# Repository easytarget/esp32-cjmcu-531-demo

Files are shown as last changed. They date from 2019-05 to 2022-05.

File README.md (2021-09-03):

 `y'know Travis is beginning to tick me off`

# CJMCU-531 and ESP32 Demo using a VL53L1X library and Ajax to display on a self-hosted site.
## A crude, slow(ish), low fidelity Lidar system
 
Designed (initially) for the commonly available VL53L1X (4 meter) IR Time Of Flight sensor from ST Microelectronics:
https://www.st.com/en/imaging-and-photonics-solutions/vl53l1x.html

Using this in can be as easy as connecting to the `VL53L1X-demo` wifi network (no password needed), and then browsing to `192.168.4.1` for the UI. Other WiFi settings can be used of course, see comments.

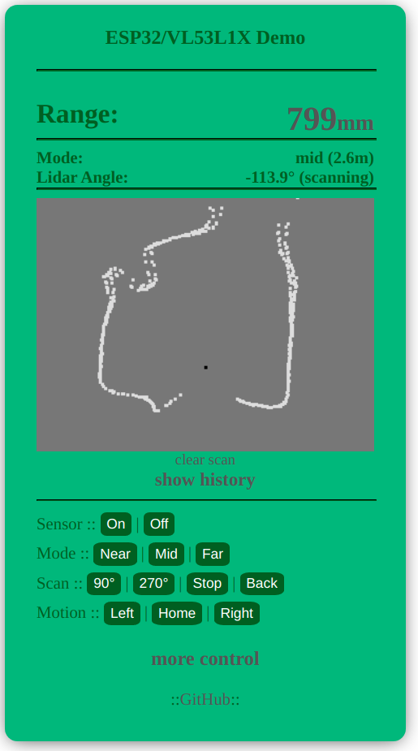
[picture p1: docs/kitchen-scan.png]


The goal of this project is to prove the suitability of this sensor for a small-scale LIDAR scanner to be used in domestic automation; robot vaccum cleaners, security robots, monitoring systems and, in my case, a K9 'companion' robot I am working on as a long-term plan.

The VL53L1X is just one of a range of similar Time-Of-Flight sensors from ST Micro. This sketch should be easily adaptable for them all, and other manufacturers have their own sensors which may also be suitable.

I have been pleasently surprised that the results are better than I expected; the scan above is of my Kitchen; here is what it looks like in reality, the sensor is the little black dot in the scan, and the little red light in the photo.

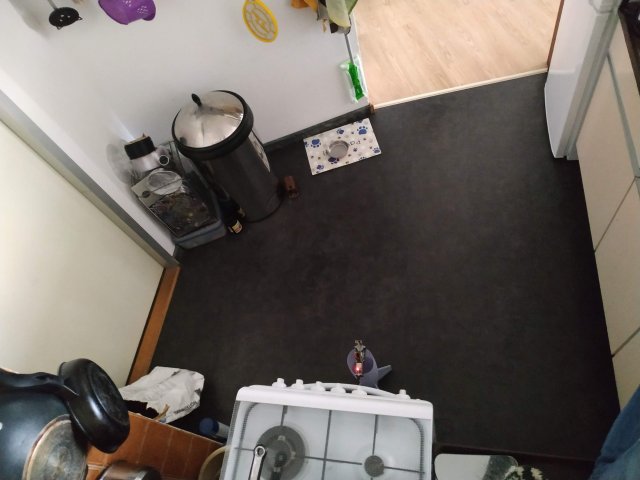
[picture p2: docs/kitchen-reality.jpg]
The Source


### Requirements:
#### Hardware:`
* ESP32 DEV module connected to a suitable sensor module; any ESP 32 module should be suitable, but you may need to adapt pinouts.
* I use a CJMCU-531 sensor carrier module, these are freely available online from AliExpress and the like. There are other VL53L1 carrier modules and boards available, all should work with this.
* For the LIDAR scan mechanism I have a 5V stepper motor with gearbox, plus the H-Bridge control board supplied with it. These are very common and can be found on AliExpress, Ebay, hobby electronics stores etc. for a couple of Euros.

#### Software:
I use the standard Arduino IDE to develop and program the unit. You need to install the ESP development board definitions and libraries using the instructions at https://docs.espressif.com/projects/arduino-esp32/en/latest/installing.html

The following 3rd party libraries are needed. They are not installed as standard in the Arduino IDE but are searchable and installable from within the library manager.
* Sparkfun VL53L1X library: https://github.com/sparkfun/SparkFun_VL53L1X_Arduino_Library/
* ArduinoJson library (v1.6+): https://arduinojson.org/

Select the dev board you are using from the boards manager list (normally the default generic ESP32 dev board entry) and select 'Minimal SPIFFS (1.9MB app with OTA..)' as your partition table type unless you have disabled Over The Air updates. See [this](/docs/programming.png).

By default the unit will create a passwordless AccessPoint named `VL53L1X-demo`, you can connect to that and browse to `http://192,168,4,1/` to see the demo. Alternatively rename the file `mywifi.sample.h` to `mywifi.h` and fill in your own details to connect to existing networks or make a more secure AP.

### A note on Sensor Libraries
Currently I use the Sparkfun library; but there is also one from Pololu: https://github.com/pololu/vl53l1x-arduino & https://www.pololu.com/product/3415/resources

Both of these are 'light' libs designed for ATMega arduinos (eg limited RAM, etc). The Official ST lib is larger, but more complete and (arguably) better supported. It is also somewhat crankily documented, and requires a sign-up at stmicro .com to access.

The ST lib itself is redistributable, although the detailed documentation is not.. I still plan to move to this; and will provide it with the codebase here.
See: https://www.st.com/en/ecosystems/x-cube-53l1a1.html#overview

### Construction

A rather minimalist guide here, I'm afraid. I have a more descriptive set of instructions, phopos and a parts list on the Hackaday page for this project:
https://hackaday.io/project/168327-cheap-and-cheerful-lidar-demo-and-dev-system

You need to follow the pinout guide here to connect the sensor and your development board together. Similarlarly for the stepper and it's H-Board driver card. And you need to maount the boards and sensor somehow. A simple design for 3d-printing with a 51x28mm 15 pin/side devboard is in the repo, as is a scadfile that can be adapted for other sizes of board(s), see line (#32)[https://github.com/easytarget/esp32-cjmcu-531-demo/blob/master/3dPrints/lidar-stand.scad#L32] for dimensioning.

#### Pins:
1. **3v3** on ESP32 goes to **VCC** on CJMCU-531
1. **GND** on ESP32 goes to **GND** on CJMCU-531
1. **D21** (GPIO21, I2C SDA) on ESP32 goes to **SDA** on CJMCU-531
1. **D22** (GPIO22, I2C SCL) on ESP32 goes to **SCL** on CJMCU-531

Not currently used, but would be required for multi-sensor or low power sentinel use.

5. _**D5** (GPIO5) on ESP32 goes to **XSHUT** on CJMCU-531 (shutdown control)_
5. _**D18** (GPIO18) on ESP32 goes to **GPIO1** on CJMCU-531 (interrupt line)_

If you are using a H-bridge driven Servo the default pins (easily changable in code) are:

7. _**D27**_ (GPIO27), _**D25**_ (GPIO25), _**D26**_ (GPIO26), _**D33**_ (GPIO23) on ESP32 should go to the respective 1,2,3,4, inputs on the H-Bridge driver.
7. **5v** and **GND** on the ESP32 are used for the stepper power supply; this places a reasonable demand on the USB power supply. Lockups and disconnects associated with motor movement are undoubtedly caused by the USB supply dipping and causing brownouts, use a decent PSU and cable.

### Demo setup
The WebUI for the demo is optimised for mobile phone displays, I run the unit in AP mode and connect from my Mobile. This allows me to demo to others easily too. 
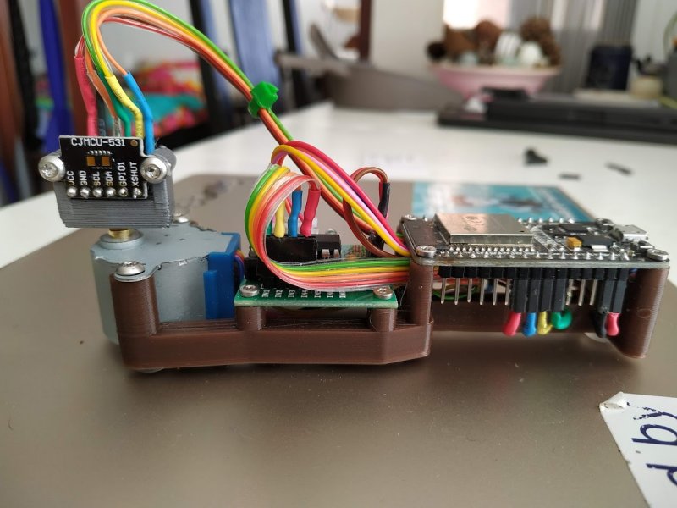
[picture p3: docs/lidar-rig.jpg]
The Prototype


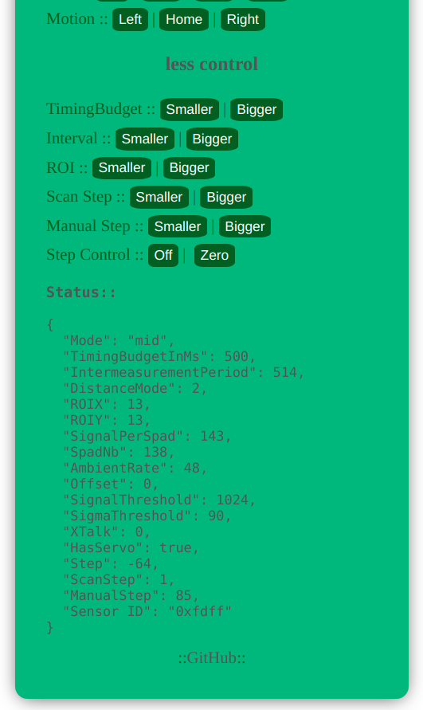
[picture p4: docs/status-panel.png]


### Future Plans
https://github.com/easytarget/esp32-cjmcu-531-demo/issues
* Move to the Official ST micro libs
* SMP: handle sensor+servo on different core than the web server.
* stop using GET requests and move to a streaming protocol.

#### Contributing
* Fork the repo
* Make a branch with a sensible nraeme in your forked repo and commit changes to that
* Make a PR in this repo against your remote fork and branch
* Explain what you are doing and don't be slapdash.. I hate random.

### Issues
The scanning action is driven by successful sending of the data to the web client. It is affected by network timeouts, packet drops and delays, these will make the scan action intermittent and somewhat laggy.. This would be resolved by implementing the data stream/smp plans above.

I have noticed the CJMCU-531 I2C comms seem to lock up infrequently, and needed a full power cycle to resume. This has only happened when I'm reflashing, rebooting and developing heavily; it seems stable when left in operation and not being 'messed' with. 

### Base/Stand/Bracket
I have included model files I used for my development board (JoyIT NodeMCU) and a paramatised SCAD file that can accomodate other MCU and Stepper driver board sizes by adjusting the relevant settings.

Two different sensor mounts are provided; the v2(taller) one also mounts the sensor at a slight angle to avoid rangefinding the edge of the table, I have found that for best results I need to stand the unit on a box or vase.
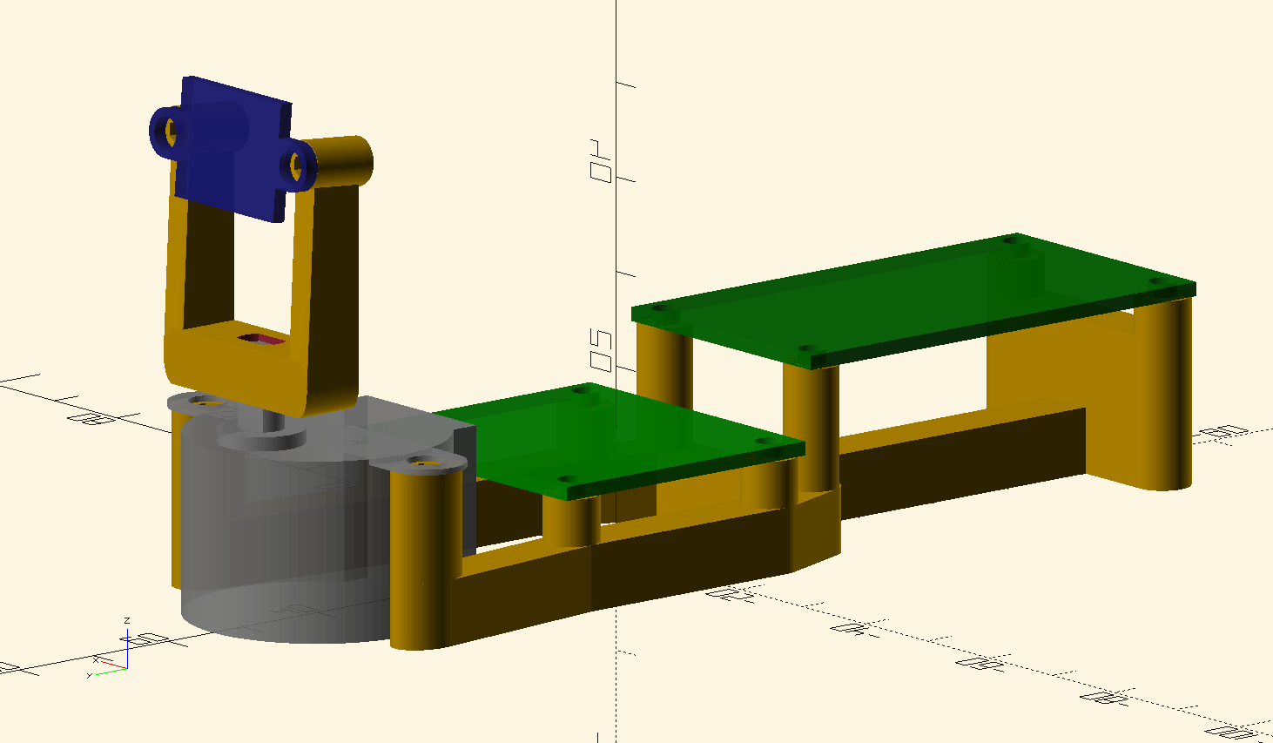
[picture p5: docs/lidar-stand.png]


### EndGoal:
Use a ESP32-CAM instead of the dev board, stream video, take pictures, record ranges all in one.

Then link that via Serial and level converters to a ATMega328 based robot chassis I already have; and go for a WiFi drive.
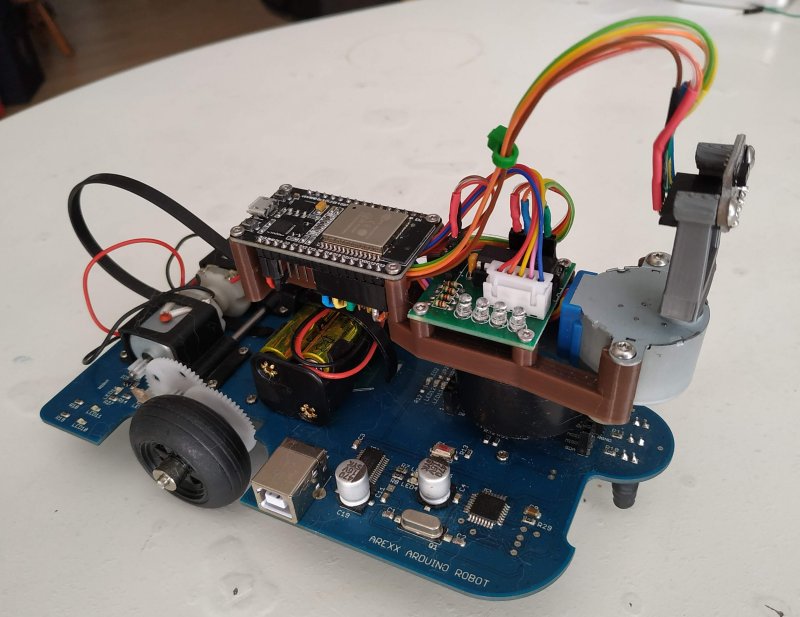
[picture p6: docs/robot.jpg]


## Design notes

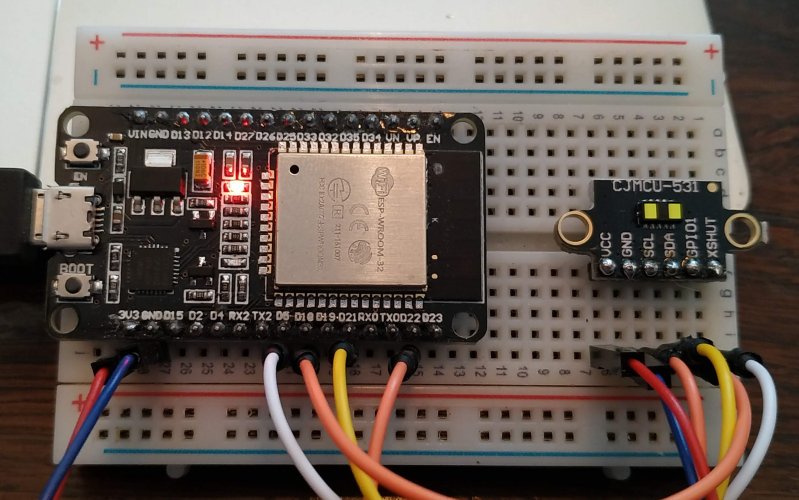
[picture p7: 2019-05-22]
docs/rangefinder-proto1.jpg

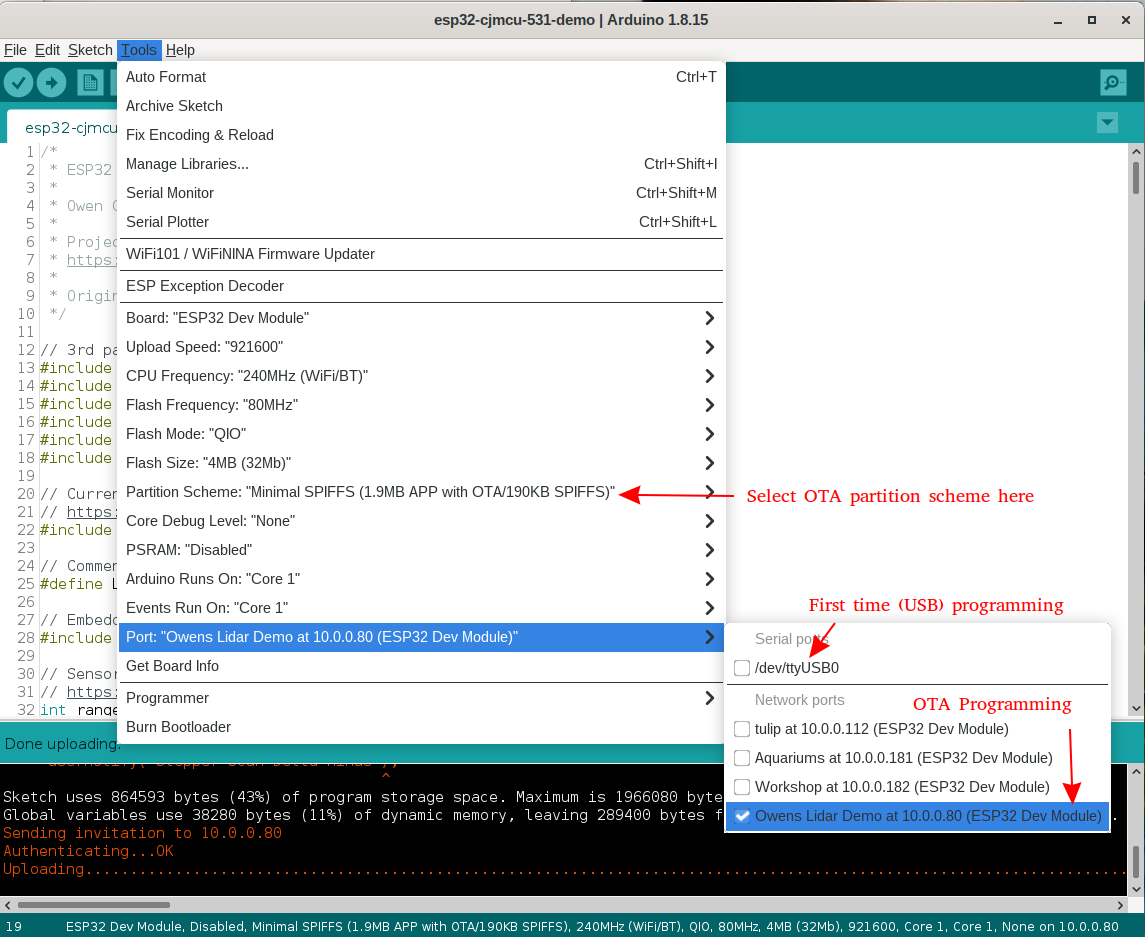
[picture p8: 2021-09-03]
docs/programming.png

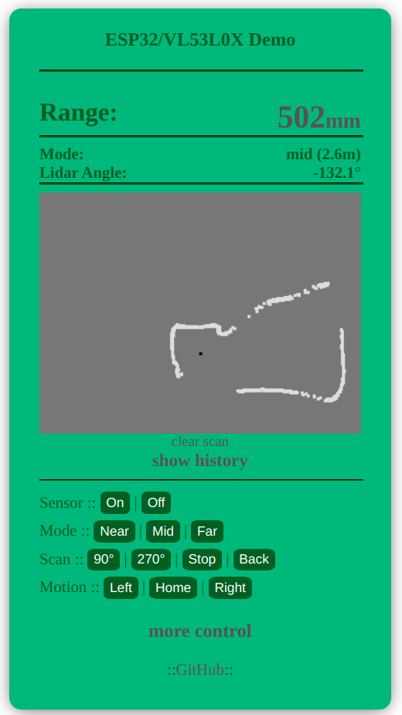
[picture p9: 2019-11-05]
docs/graph-panel.png

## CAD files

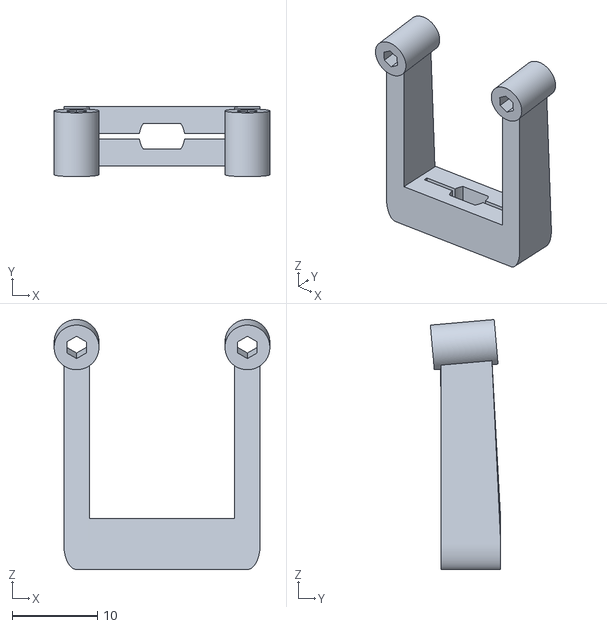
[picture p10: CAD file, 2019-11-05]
3dPrints/lidar-stand-mount-v2.stl
25.2 x 8.23 x 29.3

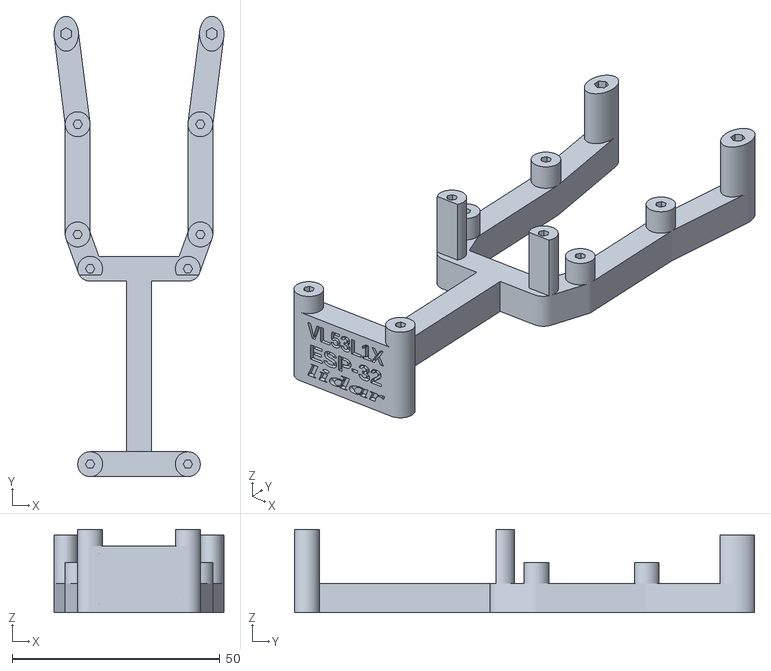
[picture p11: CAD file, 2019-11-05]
3dPrints/lidar-stand-base.stl
40.9 x 110.7 x 20.0

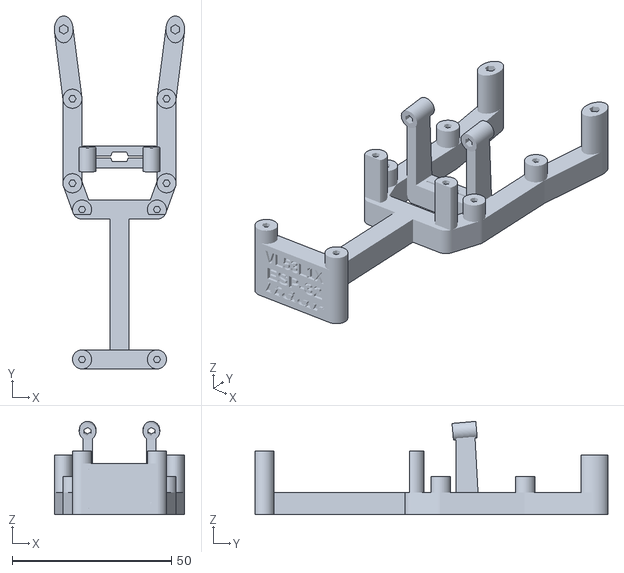
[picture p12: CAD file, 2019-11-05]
3dPrints/lidar-stand-set.stl
40.9 x 110.7 x 29.3

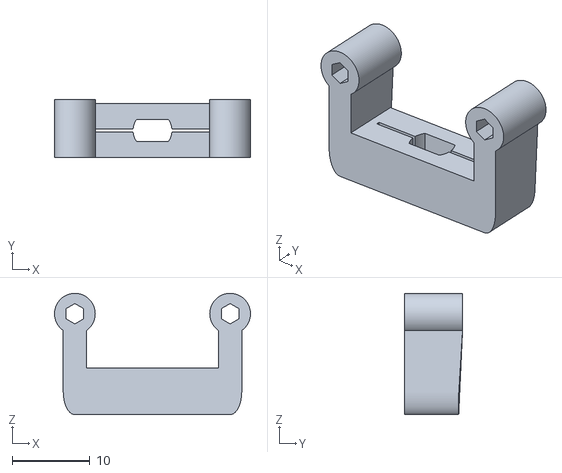
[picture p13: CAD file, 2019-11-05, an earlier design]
3dPrints/lidar-stand-mount-v1.stl
25.2 x 7.50 x 15.6

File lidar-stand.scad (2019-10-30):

// Lidar Base
// A bit overdone, but works OK. 
// Wayyy too many parameters, but Boards are resizable
//  and can be moved relative to each other.

$fn=90;

fitting=!true;

stand();

mcuY = -40;
drvY = 5;
motY = 40;
// tofs prefix used for flight sensor


if (fitting) 
    mount(pos=[0,motY+motsoffset-3.5,40],rot=-90);
else
    mount([0,-3.5,16],-90); 
    
if (fitting) {
    color("darkgreen",0.8) mcu(pos=[0,mcuY,20]);
    color("green",0.8) drv(pos=[0,drvY,12]);
    color("grey",0.8) mot(pos=[0,motY,0]);
    color("midnightblue",0.8) tof(pos=[0,motY+motsoffset+5.5,37]);
}

// Parts & Dimensions

mcuholeX=23.5;
mcuholeY=47;
mcuholeD=3;
mcuboardX=28.7;
mcuboardY=51.7;

drvholeX=29.5;
drvholeY=26.5;
drvholeD=3;
drvboardX=34.5;
drvboardY=32;

motdia=28;
mothigh=19.25;
motwireout=17.5;
motholeW=35;
motholeD=4.2;
motshaft=5;
motsflat=3;
motsoffset=7.5;
motsbossD=9.3;
motsl=8.5; 

tofsholeW=20;
tofsholeD=3.5;
tofsboardH=12.5;
tofsboardW=15.8;



module mount(pos=[0,0,0],rot=0) 
    translate(pos) rotate([rot,0,0]) {
    linear_extrude(height=7.5) {
        translate([-tofsholeW/2,3])
        difference() {
            circle(d=tofsholeD*1.5);
            rotate(30) circle(d=tofsholeD*0.75,$fn=6);
        }
        translate([tofsholeW/2,3])
        difference() {
            circle(d=tofsholeD*1.5);
            rotate(30) circle(d=tofsholeD*0.75,$fn=6);
        }
    }
    difference() {
        hull () {
            translate([10,13,0]) scale([0.5,1,1])
            cylinder(d=6,h=7);
            translate([-10,13,0]) scale([0.5,1,1])
            cylinder(d=6,h=7);
        }
        translate([0,13,3.5])
        rotate([90,0,0])
        intersection() {
            cylinder(d=motshaft,h=7,center=true);
            cube([motshaft,motsflat-0.2,7],center=true);
        }
        translate([0,13,3.5])
        cube([15,7,0.4],center=true);
    }
    hull () {
        translate([10,13,0]) scale([0.5,1,1])
        cylinder(d=6,h=7);
        translate([10,5,0]) scale([1,0.1,1])
        cylinder(d=3,h=7.5);
    }
    hull () {
        translate([-10,13,0]) scale([0.5,1,1])
        cylinder(d=6,h=7);
        translate([-10,5,0]) scale([1,0.1,1])
        cylinder(d=3,h=7.5);
    }
}
    

module stand() {
    // motor pins
    translate([0,motY,0])
    linear_extrude(height=mothigh-0.6) {
        for(x=[-0.5,0.5]) {
            translate([motholeW*x,0])
            difference() {
                scale([0.7,1]) circle(r=motholeD);
                rotate(30) circle(d=motholeD*0.7,$fn=6);
            }
        }
    }

    // driver pins
    translate([0,drvY,0])
    linear_extrude(height=12) {
        for(x=[-0.5,0.5],y=[-0.5,0.5]) {
            translate([drvholeX*x,drvholeY*y])
            difference() {
                circle(r=drvholeD);
                circle(d=drvholeD*0.75,$fn=6);
            }
        }
    }
        
    // mcu pins
    translate([0,mcuY,0]) 
    linear_extrude(height=20) difference() {
            for(x=[-0.5,0.5],y=[-0.5,0.5]) {
                translate([mcuholeX*x,mcuholeY*y])
                difference() {
                    circle(r=mcuholeD);
                    circle(d=mcuholeD*0.75,$fn=6);
                }
            }
            translate([-mcuboardX,mcuholeY/2-7])
            square([mcuboardX*2,5.5]);
    }

    // chassis, hull city
    linear_extrude(height=7) {
        hull() {
            translate([mcuholeX/2,mcuholeY/2+mcuY])
            circle(r=mcuholeD);
            translate([-mcuholeX/2,mcuholeY/2+mcuY])
            circle(r=mcuholeD);
        }
        hull() {
            translate([mcuholeX/2,mcuholeY/2+mcuY])
            circle(r=mcuholeD);
            translate([drvholeX/2,-drvholeY/2+drvY])
            circle(r=drvholeD);
        }
        hull() {
            translate([-mcuholeX/2,mcuholeY/2+mcuY])
            circle(r=mcuholeD);
            translate([-drvholeX/2,-drvholeY/2+drvY])
            circle(r=drvholeD);
        }
        hull() {
            translate([drvholeX/2,drvholeY/2+drvY])
            circle(r=drvholeD);
            translate([drvholeX/2,-drvholeY/2+drvY])
            circle(r=drvholeD);
        }
        hull() {
            translate([-drvholeX/2,drvholeY/2+drvY])
            circle(r=drvholeD);
            translate([-drvholeX/2,-drvholeY/2+drvY])
            circle(r=drvholeD);
        }
        hull() {
            translate([-drvholeX/2,drvholeY/2+drvY])
            circle(r=drvholeD);
            translate([-motholeW/2,motY])
            scale([0.7,1]) circle(r=motholeD);
        }
        hull() {
            translate([drvholeX/2,drvholeY/2+drvY])
            circle(r=drvholeD);
            translate([motholeW/2,motY])
            scale([0.7,1]) circle(r=motholeD);
        }
    }
    difference() {
        union() {
            linear_extrude(height=16,convexity=10)
            hull() {
                translate([mcuholeX/2,mcuY-mcuholeY/2])
                circle(r=mcuholeD);
                translate([-mcuholeX/2,mcuY-mcuholeY/2])
                circle(r=mcuholeD);
            }
            linear_extrude(height=7,convexity=10)
            hull() {
                translate([0,mcuholeY/2+mcuY])
                circle(r=mcuholeD);
                translate([0,-mcuholeY/2+mcuY])
                circle(r=mcuholeD);
            }
        }
        translate([0,mcuY-mcuholeY/2-2,11])
        rotate([90,0,0])
        linear_extrude(height=4,convexity=10)
        scale([0.34,0.35,1])
        text("VL53L1X",halign="center",font="Liberation Sans:style=Bold");
        translate([0,mcuY-mcuholeY/2-2,6])
        rotate([90,0,0])
        linear_extrude(height=4,convexity=10)
        scale([0.4,0.35,1])
        text("ESP-32",halign="center",font="Liberation Sans:style=Bold");
        translate([0,mcuY-mcuholeY/2-2,2])
        rotate([90,0,0])
        linear_extrude(height=4,convexity=10)
        scale([0.75,0.3,1])
        text("lidar",halign="center",font="Liberation Serif:style=Bold Italic");
   }
}


module mcu(pos=[0,0,0]) translate(pos) {
    linear_extrude(height=1.5) {
        difference() {
            square([mcuboardX,mcuboardY],center=true);
            for (x=[-0.5,0.5],y=[-0.5,0.5]) {
                translate([mcuholeX*x,mcuholeY*y])
                circle(d=mcuholeD);
            }
        }
    }
}

module drv(pos=[0,0,0]) translate(pos) {
    linear_extrude(height=1.5) {
        difference() {
            square([drvboardX,drvboardY],center=true);
            for (x=[-0.5,0.5],y=[-0.5,0.5]) {
                translate([drvholeX*x,drvholeY*y])
                circle(d=drvholeD);
            }
        }
    }
}

module mot(pos=[0,0,0]) translate(pos) {
    linear_extrude(height=mothigh) {
        circle(d=motdia);
        translate([0,-motdia/2+2])
        square([motwireout,4],center=true);
    }
    translate([0,0,mothigh-0.6])
    linear_extrude(height=0.6) {
        difference() {
            hull() {
                translate([-motholeW/2,0])
                circle(r=motholeD);
                translate([motholeW/2,0])
                circle(r=motholeD);
            }
            translate([-motholeW/2,0])
            circle(d=motholeD);
            translate([motholeW/2,0])
            circle(d=motholeD);
        }
    }
    translate([0,motsoffset,mothigh])
    cylinder(d=motsbossD,h=1.5);
    translate([0,motsoffset,mothigh+1.5])
    intersection() {
        cylinder(d=motshaft,h=motsl);
        translate([-motshaft/2,-motsflat/2,0])
        cube([motshaft,motsflat,motsl]);
    }
    
}

module tof(pos=[0,0,0],rot=90) 
    translate(pos) rotate([rot,0,0]) {
    linear_extrude(height=1.5) {
        square([tofsboardW,tofsboardH],center=true);
        difference() {
            hull() {
                translate([-tofsholeW/2,0])
                circle(d=tofsholeD*1.5);
                translate([tofsholeW/2,0])
                circle(d=tofsholeD*1.5);
            }
            translate([-tofsholeW/2,0])
            circle(d=tofsholeD);
            translate([tofsholeW/2,0])
            circle(d=tofsholeD);
        }
    }
}

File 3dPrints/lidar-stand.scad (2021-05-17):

// Lidar Base
// A bit overdone, but works OK. 
// All the dimensions of the Boards are resizable
//  and boards can be moved relative to each other 
//  for clearance.

$fn=90;

// Fitting mode is good for getting the design right
fitting=!false;

// Parts & Dimensions

// ESP32 Dev Board 
// (this can vary, there are many 'standard' dev board layouts for the ESP32)
esp32BoardX=28.7;  // overall board dimensions
esp32BoardY=51.7;
esp32Holex=23.5;   // holes (assume common centre to board)
esp32HoleY=47;
esp32HoleD=3;      // hole diameter

// Stepper Motor H-Bridge driver board
hBridgeBoardX=34.5;
hBridgeBoardY=32;
hBridgeHoleX=29.5;
hBridgeHoleY=26.5;
hBridgeHoleD=3;

// Stepper Motor
stepperMotorDiameter=28;
stepperMotorHeight=19.25;
stepperMotorWireout=17.5;
stepperMotorHoleW=35;
stepperMotorHoleD=4.2;
stepperMotorShaft=5;
stepperMotorShaftFlat=3;
stepperMotorShaftOffset=7.5;
stepperMotorShaftBossDiameter=9.3;
stepperMotorShaftLength=8.5; 

// VL53L1X module
sensorBoardH=12.5;
sensorBoardW=15.8;
sensorHoleW=20;
sensorHoleD=3.5;

// Offsets for boards along Y axis (length)
esp32Y = -40;
hBridgeY = 5;
stepperMotorY = 40;

// Lay the parts out
if (!fitting)  {
    stand();
    mount([0,50,26],-90); 
} else {
    stand();
    mount(pos=[0,stepperMotorY+stepperMotorShaftOffset-3.5,50],rot=-90);
    color("darkgreen",0.8) esp32(pos=[0,esp32Y,20]);
    color("green",0.8) hBridge(pos=[0,hBridgeY,12]);
    color("grey",0.8) stepperMotor(pos=[0,stepperMotorY,0]);
    color("midnightblue",0.8) sensor(pos=[0,stepperMotorY+stepperMotorShaftOffset+4.5,50.7],rot=95);
}

// The VL53L1X sensor mount (yoke)
module mount(pos=[0,0,0],rot=0) translate(pos) rotate([rot,0,0]) {
    translate([0,0,-1]) rotate([5,0,0])
    linear_extrude(height=7.5) {
        translate([-sensorHoleW/2,0])
        difference() {
            circle(d=sensorHoleD*1.5);
            rotate(30) circle(d=sensorHoleD*0.75,$fn=6);
        }
        translate([sensorHoleW/2,0])
        difference() {
            circle(d=sensorHoleD*1.5);
            rotate(30) circle(d=sensorHoleD*0.75,$fn=6);
        }
    }
    difference() {
        hull () {
            translate([10,23,0]) scale([0.5,1,1])
            cylinder(d=6,h=7);
            translate([-10,23,0]) scale([0.5,1,1])
            cylinder(d=6,h=7);
        }
        translate([0,23,3.5])
        rotate([90,0,0])
        intersection() {
            cylinder(d=stepperMotorShaft+0.3,h=7,center=true);
            cube([stepperMotorShaft+1,stepperMotorShaftFlat,7],center=true);
        }
        translate([0,23,3.5])
        cube([15,7,0.6],center=true);
    }
    hull () {
        translate([10,23,0]) scale([0.5,1,1])
        cylinder(d=6,h=7);
        translate([10,2,0])
        rotate([5,0,0])
        scale([1,0.1,1]) 
        cylinder(d=3,h=6);
    }
    hull () {
        translate([-10,23,0]) scale([0.5,1,1])
        cylinder(d=6,h=7);
        translate([-10,2,0])
        rotate([5,0,0])
        scale([1,0.1,1])
        cylinder(d=3,h=6);
    }
}

// The main base/stand for the unit
module stand() {
    // motor mounts
    translate([0,stepperMotorY,0])
    linear_extrude(height=stepperMotorHeight-0.6) {
        for(x=[-0.5,0.5]) {
            translate([stepperMotorHoleW*x,0])
            difference() {
                scale([0.7,1]) circle(r=stepperMotorHoleD);
                rotate(30) circle(d=stepperMotorHoleD*0.7,$fn=6);
            }
        }
    }

    // driver mounts
    translate([0,hBridgeY,0])
    linear_extrude(height=12) {
        for(x=[-0.5,0.5],y=[-0.5,0.5]) {
            translate([hBridgeHoleX*x,hBridgeHoleY*y])
            difference() {
                circle(r=hBridgeHoleD);
                circle(d=hBridgeHoleD*0.75,$fn=6);
            }
        }
    }
        
    // esp32 mounts
    translate([0,esp32Y,0]) 
    linear_extrude(height=20) difference() {
            for(x=[-0.5,0.5],y=[-0.5,0.5]) {
                translate([esp32Holex*x,esp32HoleY*y])
                difference() {
                    circle(r=esp32HoleD);
                    circle(d=esp32HoleD*0.75,$fn=6);
                }
            }
            // some clearance is needed for the pins on the esp32 board
            translate([-esp32BoardX,esp32HoleY/2-7])
            square([esp32BoardX*2,5.5]);
    }

    // ithe rest of the chassis, too many hull()s for my liking...
    linear_extrude(height=7) {
        hull() {
            translate([esp32Holex/2,esp32HoleY/2+esp32Y])
            circle(r=esp32HoleD);
            translate([-esp32Holex/2,esp32HoleY/2+esp32Y])
            circle(r=esp32HoleD);
        }
        hull() {
            translate([esp32Holex/2,esp32HoleY/2+esp32Y])
            circle(r=esp32HoleD);
            translate([hBridgeHoleX/2,-hBridgeHoleY/2+hBridgeY])
            circle(r=hBridgeHoleD);
        }
        hull() {
            translate([-esp32Holex/2,esp32HoleY/2+esp32Y])
            circle(r=esp32HoleD);
            translate([-hBridgeHoleX/2,-hBridgeHoleY/2+hBridgeY])
            circle(r=hBridgeHoleD);
        }
        hull() {
            translate([hBridgeHoleX/2,hBridgeHoleY/2+hBridgeY])
            circle(r=hBridgeHoleD);
            translate([hBridgeHoleX/2,-hBridgeHoleY/2+hBridgeY])
            circle(r=hBridgeHoleD);
        }
        hull() {
            translate([-hBridgeHoleX/2,hBridgeHoleY/2+hBridgeY])
            circle(r=hBridgeHoleD);
            translate([-hBridgeHoleX/2,-hBridgeHoleY/2+hBridgeY])
            circle(r=hBridgeHoleD);
        }
        hull() {
            translate([-hBridgeHoleX/2,hBridgeHoleY/2+hBridgeY])
            circle(r=hBridgeHoleD);
            translate([-stepperMotorHoleW/2,stepperMotorY])
            scale([0.7,1]) circle(r=stepperMotorHoleD);
        }
        hull() {
            translate([hBridgeHoleX/2,hBridgeHoleY/2+hBridgeY])
            circle(r=hBridgeHoleD);
            translate([stepperMotorHoleW/2,stepperMotorY])
            scale([0.7,1]) circle(r=stepperMotorHoleD);
        }
    }
    difference() {
        union() {
            linear_extrude(height=16,convexity=10)
            hull() {
                translate([esp32Holex/2,esp32Y-esp32HoleY/2])
                circle(r=esp32HoleD);
                translate([-esp32Holex/2,esp32Y-esp32HoleY/2])
                circle(r=esp32HoleD);
            }
            linear_extrude(height=7,convexity=10)
            hull() {
                translate([0,esp32HoleY/2+esp32Y])
                circle(r=esp32HoleD);
                translate([0,-esp32HoleY/2+esp32Y])
                circle(r=esp32HoleD);
            }
        }
        translate([0,esp32Y-esp32HoleY/2-2,11])
        rotate([90,0,0])
        linear_extrude(height=4,convexity=10)
        scale([0.34,0.35,1])
        text("VL53L1X",halign="center",font="Liberation Sans:style=Bold");
        translate([0,esp32Y-esp32HoleY/2-2,6])
        rotate([90,0,0])
        linear_extrude(height=4,convexity=10)
        scale([0.4,0.35,1])
        text("ESP-32",halign="center",font="Liberation Sans:style=Bold");
        translate([0,esp32Y-esp32HoleY/2-2,2])
        rotate([90,0,0])
        linear_extrude(height=4,convexity=10)
        scale([0.75,0.3,1])
        text("lidar",halign="center",font="Liberation Serif:style=Bold Italic");
   }
}


module esp32(pos=[0,0,0]) translate(pos) {
    linear_extrude(height=1.5) {
        difference() {
            square([esp32BoardX,esp32BoardY],center=true);
            for (x=[-0.5,0.5],y=[-0.5,0.5]) {
                translate([esp32Holex*x,esp32HoleY*y])
                circle(d=esp32HoleD);
            }
        }
    }
}

module hBridge(pos=[0,0,0]) translate(pos) {
    linear_extrude(height=1.5) {
        difference() {
            square([hBridgeBoardX,hBridgeBoardY],center=true);
            for (x=[-0.5,0.5],y=[-0.5,0.5]) {
                translate([hBridgeHoleX*x,hBridgeHoleY*y])
                circle(d=hBridgeHoleD);
            }
        }
    }
}
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

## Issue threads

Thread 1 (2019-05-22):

UI quicklist

easytarget, 2019-05-22:
* Meter marks on graph, persistent. Use globalCompositeOperation to show through fill. Create a column draw function with width attr for blanking.
*  ~~better value display feedback~~
* ~~Settings panel~~
* ~~Angle display if servo enabled..~~
* ~~Kill the 'selected' highlighting~~
* ~~github url is wrong~~

easytarget, 2019-05-24:
just did some of this..

easytarget, 2019-11-05:
All done apart from scal marks, which I'm defining as 'wontfix'

Closed 2019-11-05.

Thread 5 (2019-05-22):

Multi sensor.

easytarget, 2019-05-22:
I need 2 for K9!
Using the xShut pin the I2C address can be programmed.
Then add sensor index stuff in code and comms so we can handle 2 sensors.
Assume all sensors share a common stepper.

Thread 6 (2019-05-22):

Wifi Improvements

easytarget, 2019-05-22:
* ~~sample wifi file~~
* multi AP selection
* properly working AP mode captive portal - harder to do than I thought.. need to look for a proper library for this since the examples given are horrible

easytarget, 2019-05-26:
Done some of this, but I want to use https://github.com/zhouhan0126/WIFIMANAGER-ESP32 in final version.

easytarget, 2019-11-05:
I'm not sure about the WifiManager stuff, I'd like to be able to use this as a AP in it's own right, as well as on other networks and the above library does not facilitate that very well.
I think I prefer this as-is. Closing.

Closed 2019-11-05.

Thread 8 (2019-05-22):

Rationalise the URL handler list

easytarget, 2019-05-22:
Currently I have a handler per event; this needs to be resolved to one handler per control.
* I assume I can access the full URL..
* Does the wifiServer lib allow me to easily parse options?

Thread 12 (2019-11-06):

Calibration Controls

easytarget, 2019-11-06:
the sensor has calibration modes for both distance, and signal (reflections etc).
It might be nice to expose these in the interface.

tomarigr, 2020-04-12:
Hi, thank you for this project. Calibration is very important and would be nice if it was supported and aided by the fw.
Im planning to design a 3d printed base for the motor, and use qi wireless for the sensor to allow for full 360 rotation. I have the electronics ready, but my sensor needs calibration. It would be nice if there was a painless way to do it.

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

easytarget, 2020-07-28:
Looks very cool, Bbig thanks for taking the time to feedback etc.
I'm trying to drag this and other projects back into some form of active development, this looks like a good first step to me. Should be (relatively) easy since it is just an extension to existing UI elements, not something new.
I'll have to think about prompting the user to put calibration targets in place..

I like the use of QI for this, I assume you are spinning the whole unit including the motor? I had thought of using a commutator ring to supply power (they are OK for power, lousy for data) and then having the whole rig rotate lollipop like above that.  QI would eliminate the commutator nicely..

tomarigr, 2020-07-28:
Hi, the motor body is still, on the shaft I clamp a platform and the hole sensor + esp8266 + qi reciever + optical sensor spins around. The optical sensor is needed so you know where the distance sensor is looking at. I took it out of an old inkjet printer or you can buy it for £3 from AliExpress. Proof of concept works, but its sitting inside the "to play with later" box because of the calibration issue. Kudos for what you've done so far.

tomarigr, 2020-07-28:
Just to make this clear, motor takes direct power, qi powers only esp + sensors. This is because I thought the motor will introduce noise and esp doesn't like noisy power plus that it might be hard for the qi reciever to afford powering

easytarget, 2020-07-28:
> esp doesn't like noisy power

A big +1 to that; I've had one completely incapable of running without brownouts until I properly isolated its power from the (brushed) spindle motor it controlled.

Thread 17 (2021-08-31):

ESP IDE V2

easytarget, 2021-08-31:
Check compile and operation with 2.x IDE
https://github.com/espressif/arduino-esp32/releases/tag/2.0.0

easytarget, 2021-09-03:
All checked, compiles and runs fine with esp arduino 2.0.0

Closed 2021-09-03.

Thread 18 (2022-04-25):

text/plane is not right

MikeyMoMo, 2022-04-25:
It is text/plain

Maybe that's part of your problem.

easytarget, 2022-05-10:
I'm guessing this was a mis-typing or other weirdness, since:
```
[owen@hobbes esp32-cjmcu-531-demo]$ grep -ir 'plane' *
[owen@hobbes esp32-cjmcu-531-demo]$
```

MikeyMoMo, 2022-06-12:
It is "plain", not "plane".  That's the problem.

easytarget, 2022-06-13:
Nope, the problem is that the word 'plane' does not appear anywhere within my code and I don't know what you are talking about.
Maybe you are using somebody else's fork? or are otherwise confused.

Closed 2022-05-10.

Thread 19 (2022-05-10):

Lidar angle can show rounding errors

easytarget, 2022-05-10:
We should format the displayed string in js on the browser and stop doing roundf on line 582 of the sketch

easytarget, 2022-05-10:
Fixed by 30810fde95

Closed 2022-05-10.

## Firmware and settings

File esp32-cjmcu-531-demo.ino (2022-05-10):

/*
 * ESP32 AJAX Rangefinder and Lidar demo
 * 
 * Owen Carter (https://easytarget.org/)
 * 
 * Project home @
 * https://github.com/easytarget/esp32-cjmcu-531-demo/
 * 
 * Originally based on examples from Sparkfun and https://circuits4you.com
 */
 
// 3rd party libraries
#include <WiFi.h>
#include <WiFiClient.h>
#include <WebServer.h>
#include <ArduinoJson.h>
#include <Wire.h>
#include <ArduinoOTA.h>

// Currently using the SparkFun library for the sensor: 
// https://github.com/sparkfun/SparkFun_VL53L1X_Arduino_Library/
#include <SparkFun_VL53L1X.h>

// Comment out to disable servo (lidar) functionality
#define LIDAR

// Embedded web page is kept in a seperate header file (& stored in progmem)
#include "index.h"

// Sensor setup; see:
// https://learn.sparkfun.com/tutorials/qwiic-distance-sensor-vl53l1x-hookup-guide#library-overview
int range;                 // Latest reading
int budgetIndex = 4 ;      // time budget default 100ms (bigger==more accurate but slower)
int budgetValue[7] = {15,20,33,50,100,200,500}; // // time budget steps in ms.
byte opticalCenter = 199;  // Defines the centre of the sensor, required when setting ROI

// Settings
bool enabled = true; // main enabled/disabled control
String mode = "mid"; // range mode

// Wifi
#if __has_include("mywifi.h")
  // I keep my settings in a seperate header file that is not checked into git
  #include "mywifi.h"
#else
  // Leave as is to create an accesspoint, or set ACCESSPOINT 
  //  to false and supply your networks SSID and PASSWORD.
  #define ACCESSPOINT
  #define ACCESSPOINTIP 192,168,4,1
  #define ACCESSPOINTMASK 255,255,255,1
  const char* ssid = "VL53L1X-demo";
  const char* password = ""; // no password == very insecure, but very easy to demo
#endif

#if defined (DEVICENAME)
  String myName = DEVICENAME;
#else
  String myName = "ESP32/VL53L1X Demo";
#endif

#if defined(NO_OTA)
    bool otaEnabled = false;
#else
    bool otaEnabled = true;
#endif

// Webserver
WebServer server(80);

// Distance Sensor
SFEVL53L1X distanceSensor;

/*  Wiring:  
 * 3v3 on ESP32 goes to VCC on CMJU-531
 * GND on ESP32 goes to GND on CMJU-531
 * D21 (GPIO21, I2C SDA) on ESP32 goes to SDA on CMJU-531
 * D22 (GPIO22, I2C SCL) on ESP32 goes to SCL on CMJU-531
 * D5 (GPIO5) on ESP32 goes to XSHUT on CMJU-531 (shutdown control, not currently used)
 * D18 (GPIO18) on ESP32 goes to GPIO1 on CMJU-531 (interrupt line, not currently used)
*/

// Uncomment the following lines if we start to use the shutdown and interrupt pins.
//#define SHUTDOWN_PIN 2
//#define INTERRUPT_PIN 3
//SFEVL53L1X distanceSensor(Wire, SHUTDOWN_PIN, INTERRUPT_PIN);

// Lidar Settings
// setup below assumes a H-bridge stepper driver for a small (5v Unipolar) motor
// Changes would be needed for a stepstick driver and a 'better' stepper, or a servo.

#ifdef LIDAR
  #include <Stepper.h>

  /* Wiring:
   *  Pins D27,D25,D26,D33 (aka GPIO27,25,26,33) go to the 
   *  four inut pins of a H-Bridge stepper driver.
   *  No zero or homing sensor is supported, the motors 'zero' point
   *  will initially be set to its power on position.
   *  GPIO0 (aka the 'boot' button on the Dev board) is used for
   *  a 'home and de-power' manual control.
   */
  
  // Pins, edit this if not using suggested wiring
  byte stepPin[4] = {27,25,26,33};

  // Total steps/revolution/degree for motor 
  // (5v geared motors are often multiples of 513 steps/rev)
  #define STEPS_PER_REV 2052 
  #define STEPS_PER_DEG 5.7

  // Uncomment to reverse motor movement 
  //#define SERVO_INVERT

  // Stepper speed in RPM (integer), my stepper maxes at 15rpm.
  int STEPPER_RPM = 12;
  
  // No zero/endstop support or hardware yet..
  // #define ENDSTOP_PIN unset
  
  // Soft endstops (240 degree sweep for demo unit)
  #define STEPS_MIN -769
  #define STEPS_MAX 769

  // initialize the stepper library
  Stepper lidarStepper(STEPS_PER_REV, stepPin[0], stepPin[1], stepPin[2], stepPin[3]);

  int currentStep = 0;                   // Assume servo is at '0' to start.  
  int manualStep = (STEPS_PER_REV/24);    // close to 15 degrees initially
  bool stepperPwr = 0;                   // stepper power status
  bool stepState[4] = {LOW,LOW,LOW,LOW}; // pin state during power off
  int scanStep = (STEPS_PER_REV/120);    // steps per scan reading, defaults to ~3 degrees
  int scanControl = 0;                   // 0=off, -1=stepping left, 1=stepping right
  int scanMin = 0;                       // start of scan
  int scanMax = 0;                       // end of scan
#endif

// Other
  /* Wiring:
   *  D0 (GPIO0, aka the 'boot' button on the Dev board) is used for
   *   a 'home and de-power' manual control.
   *  D2 (GPIO2) is connected to the onboard LED of the dev module
   *   and used for the notification LED.
   */
#define LED 2    // On-Board LED pin
#define BLINK 30 // On-Board LED blink time in ms

#define BUTTON 0 // 'Boot' button (homes the stepper), comment out to disable.


//===============================================================
// Setup
//===============================================================

void setup(void){
  // Misc. hardware
  pinMode(LED, OUTPUT);

  #ifdef BUTTON
    pinMode(BUTTON, INPUT_PULLUP); 
  #endif

  #ifdef LIDAR
    lidarStepper.setSpeed(STEPPER_RPM);
  #endif

  // Serial
  Serial.begin(115200);
  Serial.println();
  Serial.println(myName);
  Serial.println("Booting Sketch...");

  // Turn the LED on once serial begun
  digitalWrite(LED, HIGH); 

  // Disable power saving on WiFi to improve responsiveness
  // (https://github.com/espressif/arduino-esp32/issues/1484)
  WiFi.setSleep(false);

  #ifdef ACCESSPOINT
    // Access point
    IPAddress ourIP(ACCESSPOINTIP);
    IPAddress ourMask(ACCESSPOINTMASK);
    WiFi.mode(WIFI_AP); //Access Point mode
    WiFi.softAP(ssid, password);
    WiFi.softAPConfig(ourIP, ourIP, ourMask);
    Serial.print("Access Point started: ");
    Serial.print(ssid);
    Serial.print(":");
    Serial.println(password);
    Serial.print("AP Address: ");
    Serial.println(WiFi.softAPIP());
  #else
    // Connect to existing wifi
    WiFi.mode(WIFI_STA);
    WiFi.begin(ssid, password);
    Serial.print("Connecting to: ");
    Serial.println(ssid);
    //Wait for WiFi to connect
    int aline = 0;
    while(WiFi.waitForConnectResult() != WL_CONNECTED)
    {
      delay(1000);
      aline++;
      if (aline > 80) {
        aline = 0;
        Serial.println(".");
      }
      else
      {
        Serial.print(".");
      }
    }
    //If connection successful show IP address in serial monitor
    Serial.println("");
    Serial.print("Connected to ");
    Serial.println(ssid);
    Serial.print("IP address: ");
    Serial.println(WiFi.localIP());  //IP address assigned to your ESP
  #endif

  if (otaEnabled) {
    // Start OTA once connected
    Serial.println("Setting up OTA");
    // Port defaults to 3232
    // ArduinoOTA.setPort(3232);
    // Hostname defaults to esp3232-[MAC]
    ArduinoOTA.setHostname(myName.c_str());
    // No authentication by default
    #if defined (OTA_PASSWORD)
      ArduinoOTA.setPassword(OTA_PASSWORD);
      Serial.printf("OTA Password: %s\n\r", OTA_PASSWORD);
    #endif
    ArduinoOTA
      .onStart([]() {
        String type;
        if (ArduinoOTA.getCommand() == U_FLASH)
          type = "sketch";
        else // U_SPIFFS
          type = "filesystem";
        // NOTE: if updating SPIFFS this would be the place to unmount SPIFFS using SPIFFS.end()
        Serial.println("Start updating " + type);
      })
      .onEnd([]() {
        Serial.println("\nEnd");
      })
      .onProgress([](unsigned int progress, unsigned int total) {
        Serial.printf("Progress: %u%%\r", (progress / (total / 100)));
      })
      .onError([](ota_error_t error) {
        Serial.printf("Error[%u]: ", error);
        if (error == OTA_AUTH_ERROR) Serial.println("Auth Failed");
        else if (error == OTA_BEGIN_ERROR) Serial.println("Begin Failed");
        else if (error == OTA_CONNECT_ERROR) Serial.println("Connect Failed");
        else if (error == OTA_RECEIVE_ERROR) Serial.println("Receive Failed");
        else if (error == OTA_END_ERROR) Serial.println("End Failed");
      });
    ArduinoOTA.begin();
  } else {
    Serial.println("OTA is disabled");
  }

  // HTTP request responders
  server.on("/", handleRoot);           // Main page

  // Settings
  server.on("/near", handleNearMode);   // mode seting
  server.on("/mid", handleMidMode);     // mode seting
  server.on("/far", handleFarMode);     // mode seting
  server.on("/roiplus", handleRoiPlus);   // expand ROI
  server.on("/roiminus", handleRoiMinus); // reduce ROI
  server.on("/budgetplus", handleBudgetPlus);   // increase timing budget
  server.on("/budgetminus", handleBudgetMinus); // decrease timing budget
  server.on("/intervalplus", handleIntervalPlus);   // increase measurement interval
  server.on("/intervalminus", handleIntervalMinus); // decrease measurement interval

  // Commands
  server.on("/on", handleOn);           // Sensor Enable
  server.on("/off", handleOff);         // Sensor Disable
  #ifdef LIDAR
    server.on("/s-scan90", handleScan90);             // Start a 60degree scan
    server.on("/s-scanfull", handleScanFull);          // Start a full sweep scan
    server.on("/s-scanstop", handleScanStop);         // Stop Scanning
    server.on("/s-scanback", handleScanBack);         // Reverse Scanning
    server.on("/s-left", handleStepperLeft);          // Go left
    server.on("/s-home", handleStepperHome);          // Go to center
    server.on("/s-right", handleStepperRight);        // Go right
    server.on("/s-zero", handleStepperZero);          // Set current position as zero
    server.on("/s-off", handleStepperOff);            // power off
    server.on("/s-manualplus", handleManualStepPlus);   // increase manual delta
    server.on("/s-manualminus", handleManualStepMinus); // decrease manual delta
    server.on("/s-scanplus", handleScanStepPlus);     // increase scan delta
    server.on("/s-scanminus", handleScanStepMinus);   // decrease scan delta
  #endif

  // Info requests
  server.on("/data", handleData);     // Update of distance and status

  // Start web server
  server.begin();
  Serial.println("HTTP server started");

  // Start sensor
  Wire.begin();
  delay(250);
  if (distanceSensor.begin() == 0)
    Serial.println("Sensor online!");

  // Setup complete, turn LED off
  digitalWrite(LED, LOW);   // turn the LED off now init is successful

  // Set the sensor to it's default mode, and start it if needed
  handleMidMode();
  if (enabled == true) distanceSensor.startRanging();
}

//=========================================
// Handlers for responses to http requests
//=========================================

// Mainpage 
void handleRoot() {
  digitalWrite(LED, HIGH);          // blink the LED
  String s = MAIN_page;             //Read HTML from progmem
  server.send(200, "text/html", s); //Send web page
  digitalWrite(LED, LOW);
  Serial.print("Sent the main page to: ");
  Serial.println(server.client().remoteIP().toString());
  delay(BLINK);
  digitalWrite(LED, HIGH);          // blink again
  delay(BLINK);
  digitalWrite(LED, LOW);
}
 

void handleOn()
{
  server.send(200, "text/plain", "sensor enabled");
  usernotify("Sensor Enabled");
  enabled = true;
  distanceSensor.startRanging();
}

void handleOff()
{
  server.send(200, "text/plain", "sensor disabled");
  usernotify("Sensor Disabled");
  enabled = false;
  distanceSensor.stopRanging();
}

void handleNearMode()
{
  server.send(200, "text/plain", "near mode");
  usernotify("Near Mode");
  mode = "near"; 
  budgetIndex = 1;
  distanceSensor.setDistanceModeShort();
  distanceSensor.setTimingBudgetInMs(budgetValue[budgetIndex]);
  // from sensor datasheet; minimum intermeasurement is TimingBudget+4ms
  distanceSensor.setIntermeasurementPeriod(budgetValue[budgetIndex] + 10);
}

void handleMidMode()
{
  server.send(200, "text/plain", "mid mode");
  usernotify("Mid Mode");
  mode = "mid"; 
  budgetIndex = 2;
  distanceSensor.setDistanceModeLong();
  distanceSensor.setTimingBudgetInMs(budgetValue[budgetIndex]);
  // from sensor datasheet; minimum intermeasurement is TimingBudget+4ms
  distanceSensor.setIntermeasurementPeriod(budgetValue[budgetIndex] + 10);
}

void handleFarMode()
{
  server.send(200, "text/plain", "far mode");
  usernotify("Far Mode");
  mode = "far"; 
  budgetIndex = 4;
  distanceSensor.setDistanceModeLong();
  distanceSensor.setTimingBudgetInMs(budgetValue[budgetIndex]);
  // from sensor datasheet; minimum intermeasurement is TimingBudget+4ms
  distanceSensor.setIntermeasurementPeriod(budgetValue[budgetIndex] + 10); 
}

void handleRoiPlus()
{
  server.send(200, "text/plain", "roi plus");
  usernotify("ROI plus"); 
  int newroi = distanceSensor.getROIX() + 1;
  if (newroi > 16) newroi = 16;
  distanceSensor.setROI(newroi, newroi, opticalCenter);
}

void handleRoiMinus()
{
  server.send(200, "text/plain", "roi minus");
  usernotify("ROI Minus");
  int newroi = distanceSensor.getROIX() - 1;
  if (newroi < 4) newroi = 4;
  distanceSensor.setROI(newroi, newroi, opticalCenter);
}

void handleBudgetPlus()
{
  server.send(200, "text/plain", "budget plus");
  usernotify("Budget Plus");
  int newIndex = budgetIndex + 1;
  if (newIndex > 6) return; else budgetIndex = newIndex;
  distanceSensor.setTimingBudgetInMs(budgetValue[budgetIndex]);
  if (distanceSensor.getIntermeasurementPeriod() < (budgetValue[newIndex] + 4)) // TimingBudget+4ms minimum
    distanceSensor.setIntermeasurementPeriod(budgetValue[newIndex] + 10);
}

void handleBudgetMinus()
{
  server.send(200, "text/plain", "budget minus");
  usernotify("Budget Minus");
  int newIndex = budgetIndex - 1;
  if (newIndex < 0) return; else budgetIndex = newIndex;
  distanceSensor.setTimingBudgetInMs(budgetValue[budgetIndex]);
}

void handleIntervalPlus()
{
  server.send(200, "text/plain", "interval plus");
  usernotify("Interval Plus");
  int newinterval = distanceSensor.getIntermeasurementPeriod() + 20;
  if (newinterval > 1500) return;
  distanceSensor.setIntermeasurementPeriod(newinterval);
}

void handleIntervalMinus()
{
  server.send(200, "text/plain", "interval minus");
  usernotify("Interval Minus");
  int newinterval = distanceSensor.getIntermeasurementPeriod() - 20;
  if (newinterval < (budgetValue[budgetIndex] + 4)) // TimingBudget+4ms minimum
    newinterval = budgetValue[budgetIndex] + 10; 
  distanceSensor.setIntermeasurementPeriod(newinterval);
}

#ifdef LIDAR
  void handleScan90()
  {
    server.send(200, "text/plain", "90 degree scanning started");
    usernotify("90 Degree Scanning Started");
    scanMin = (-STEPS_PER_REV/8);
    scanMax = (STEPS_PER_REV/8);
    stepTo(scanMin);
    scanControl = 1; // start at left scan position , moving right
  }
  
  void handleScanFull()
  {
    server.send(200, "text/plain", "Full scanning started");
    usernotify("Full Degree Scanning Started");
    scanMin = STEPS_MIN;
    scanMax = STEPS_MAX;
    stepTo(scanMin);
    scanControl = 1; // start at left scan position , moving right
  }
 
  void handleScanStop()
  {
    server.send(200, "text/plain", "scanning stopped");
    usernotify("Scanning Stopped");
    scanControl = 0; // simply stop, nothing more.
  }
  
  void handleScanBack()
  {
    server.send(200, "text/plain", "scan direction reversed");
    usernotify("Scan Direction Reversed");
    if (scanControl == 1) scanControl = -1;
    else if (scanControl == -1) scanControl = 1;
  }
  
  void handleStepperLeft()
  {
    server.send(200, "text/plain", "stepper left");
    usernotify("Stepper Left");
    int newStep = currentStep - manualStep; 
    if (newStep < STEPS_MIN) stepTo(STEPS_MIN); else stepTo(newStep);
  }
  
  void handleStepperRight()
  {
    server.send(200, "text/plain", "stepper right");
    usernotify("Stepper Right");
    int newStep = currentStep + manualStep; 
    if (newStep > STEPS_MAX) stepTo(STEPS_MAX) ; else stepTo(newStep);
  }
  
  void handleStepperHome()
  {
    server.send(200, "text/plain", "stepper home");
    usernotify("Stepper Home");
    if (currentStep != 0) stepTo(0);
    stepperOff();
  }
  
  void handleStepperZero()
  {
    server.send(200, "text/plain", "stepper zero");
    usernotify("Stepper Zero");
    currentStep = 0;
  }

  void handleStepperOff()
  {
    server.send(200, "text/plain", "stepper off");
    usernotify("Stepper Off");
    stepperOff();
  }

  void handleManualStepPlus()
  {
    server.send(200, "text/plain", "stepper manual delta plus");
    usernotify("Stepper Manual Delta Plus");
    int newdelta = manualStep + 10;
    if (newdelta < 285) manualStep = newdelta;
  }
  
  void handleManualStepMinus()
  {
    server.send(200, "text/plain", "stepper manual delta minus");
    usernotify("Stepper Manual Delta Minus");
    int newdelta = manualStep - 10;
    if (newdelta >= 1) manualStep = newdelta;
  }

  void handleScanStepPlus()
  {
    int newdelta;
    server.send(200, "text/plain", "stepper scan delta plus");
    usernotify("Stepper Scan Delta Plus");
    if (scanStep < 10) newdelta = scanStep + 1; else newdelta = scanStep + 3;
    if (newdelta < 120) scanStep = newdelta;
  }
  
  void handleScanStepMinus()
  {
    int newdelta;
    server.send(200, "text/plain", "stepper scan delta minus");
    usernotify("Stepper Scan Delta Minus");
    if (scanStep < 11) newdelta = scanStep - 1; else newdelta = scanStep - 3;
    if (newdelta >= 1) scanStep = newdelta;
  }
#endif

// Now come the reading request + handler

void handleData() {
  String out;
  StaticJsonDocument<450> response;
  if (enabled == true)
  {
    response["Distance"] = distanceSensor.getDistance();
    response["RangeStatus"] = distanceSensor.getRangeStatus();
  }
  else
  {
    response["Distance"] = -1;
    response["RangeStatus"] = -1;
  }
  response["Mode"] = mode;
  response["TimingBudgetInMs"] = distanceSensor.getTimingBudgetInMs();
  response["IntermeasurementPeriod"] = distanceSensor.getIntermeasurementPeriod();
  response["DistanceMode"] = distanceSensor.getDistanceMode();
  response["ROIX"] = distanceSensor.getROIX();
  response["ROIY"] = distanceSensor.getROIY();
  response["SignalPerSpad"] = distanceSensor.getSignalPerSpad();
  response["SpadNb"] = distanceSensor.getSpadNb();
  response["AmbientRate"] = distanceSensor.getAmbientRate();
  response["Offset"] = distanceSensor.getOffset();
  response["SignalThreshold"] = distanceSensor.getSignalThreshold();
  response["SigmaThreshold"] = distanceSensor.getSigmaThreshold();
  response["XTalk"] = distanceSensor.getXTalk();
  #ifdef LIDAR 
    response["Angle"] = currentStep / STEPS_PER_DEG;
    response["HasServo"] = true;
    response["Step"] = currentStep;
    response["ScanStep"] = scanStep;
    response["ManualStep"] = manualStep;
    response["ScanControl"] = scanControl;
  #else
    response["HasServo"] = false;
  #endif
  char id [8]; sprintf(id, "0x%x", distanceSensor.getSensorID());
  response["SensorID"] = id;
  response["Name"] = myName;
  
  serializeJsonPretty(response, out);
  server.send(200, "text/plain", out);

  // Move sensor in a sweep when scanning.
  #ifdef LIDAR
      if (enabled == true && scanControl == -1) {
            int newStep = currentStep - scanStep; 
            if (newStep < scanMin) {
              newStep = currentStep + scanStep;
              scanControl=1;
            }
            stepTo(newStep);
            delay(40); // let stepper settle
      }
      if (enabled == true && scanControl == 1) {
            int newStep = currentStep + scanStep; 
            if (newStep > scanMax) {
              newStep = currentStep - scanStep;
              scanControl=-1;
            }
            stepTo(newStep);
            delay(40); // let stepper settle
      }
  #endif
}

//====================================
// Other functions (eg stepper handlers)
//====================================

// flash led and dump a message to log actions
void usernotify(const char message[]) {
  digitalWrite(LED, HIGH);   
  Serial.println(message);
  delay(BLINK);
  digitalWrite(LED, LOW);
}

#ifdef LIDAR
  // Go to a target position and set that as current
  void stepTo(int target) {
     if ( currentStep != target ) {   // only move if needed
      if ( !stepperPwr ) stepperOn(); // wake stepper as needed
      #ifdef SERVO_INVERT
        lidarStepper.step(-(target-currentStep));
      #else
        lidarStepper.step((target-currentStep));
      #endif
      currentStep = target;
     }
  }

  // Disable the stepper, record pin state for when we re-enable
  void stepperOff() {
    delay(40); // wait for motor to settle, it drifts otherwise
    for (byte p=0; p < 4; p++) 
    {
      stepState[p] = digitalRead(stepPin[p]);
      digitalWrite(stepPin[p],LOW);
    }
    scanControl = 0; // stop any in-progress scans
    stepperPwr = false;
  }

  // Enable the stepper, restore last pin state
  void stepperOn() {
    for (byte p=0; p < 4; p++) 
    {
      digitalWrite(stepPin[p],stepState[p]);
    }
    delay(20); // wait for motor to settle back into energised position
    stepperPwr = true;
  }
#endif

#ifdef BUTTON
  void handleButton() {
    // Button sensing and handling goes here, currently it homes the sensor..
    if (digitalRead(BUTTON) == LOW ) {
      delay(50); // crude debounce delay..
      if (digitalRead(BUTTON) == LOW) {
        // home and disable stepper
        #ifdef LIDAR
          stepTo(0);
          stepperOff();
          usernotify("Stepper homed and disabled via button");
        #else
          usernotify("Info: Button pressed");
        #endif
        // wait for button release
        while(digitalRead(BUTTON) == LOW) delay(10);
      }
    }
  }
#endif
    

//====================================
// Main Loop (invokes client handler)
//====================================

void loop(void){
  server.handleClient();
  if (otaEnabled) ArduinoOTA.handle();
  #ifdef BUTTON
    handleButton();
  #endif
}

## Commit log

2019-05-23 notes on drivers, correct device name.
2019-05-24 Remove selection highlighting in UI; rename wifi sample file so it no longer appears in the IDE
2019-05-24 relocate servo movement controls to main panel.
2019-10-30 First pass at stand with stepper mount
    [lidar-stand.scad]
2019-11-05 Stepper control and Lidar-like functions (#11)
    Address #10 and much more:
    Control of a 4-pole (unipole) stepper motor via the Arduino stepper lib
    - Manual controls:
    -- Left, right, go to zero, declare zero, power down stepper.
    - Angle feedback
    - Lidar-like scan
    -- Auto steps after each reading in a sweep pattern
    -- Graphs results in a simple polar plot
    Adds numerous small and not-so-small UI changes and fixes to support stepper and clean up the original operation.
    Stepper is configurable via a #define's in the code, demo mode without a stepper works properly.
    - TimingBudget (basic accuracy) is now settable in it's correct steps.
    - Boot button on board homes and de-powers ste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
    [lidar-stand-base.stl, lidar-stand-mount-v1.stl, lidar-stand-mount-v2.stl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]
2019-11-05 Small fixups after merging lidar changes
2019-11-05 stepper wiring notes
2019-11-06 Fix for #2, move to a single response message and asynch timing.
    [esp32-cjmcu-531-demo.ino]
2020-04-08 Very minor fixups to code, html and comments.
    [esp32-cjmcu-531-demo.ino]
2020-08-18 Build button (#13)
    Add a build status indicator button to readme, and a note on contributing
2021-05-17 Trivial Document and Scad file update (#14)
    * Trivial comment, document and Scad file update
    * Travis fixes
    [lidar-stand.scad]
2021-05-17 For travis, use the released SparkFun lib, not a clone (#15)
    * Change the travis build to use the released SaprkFun lib from the Arduino libraries manager instead of cloning it directly.
2021-06-08 Add OTA, disable all WiFi powersave, pass name
2021-09-02 Update to latest Arduino IDE
2022-05-10 send lidar angle as float and format in browser, fix #15
    [esp32-cjmcu-531-demo.ino]
